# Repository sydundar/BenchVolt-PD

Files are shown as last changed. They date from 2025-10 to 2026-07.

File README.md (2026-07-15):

<div align="center">

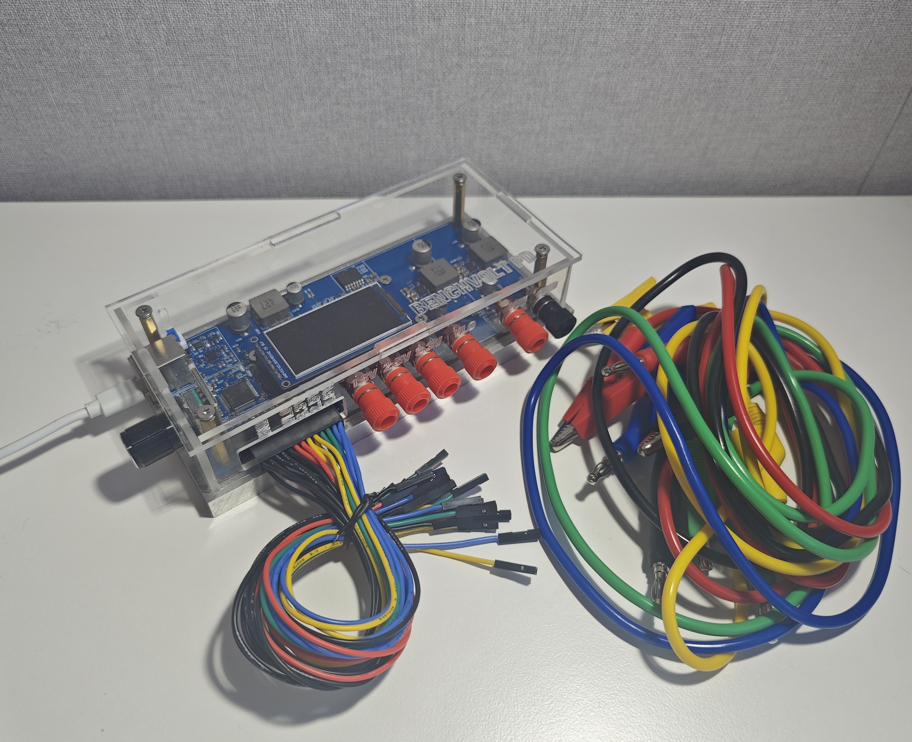
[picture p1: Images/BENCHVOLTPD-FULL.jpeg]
BenchVolt PD Full
  

  <br><br>

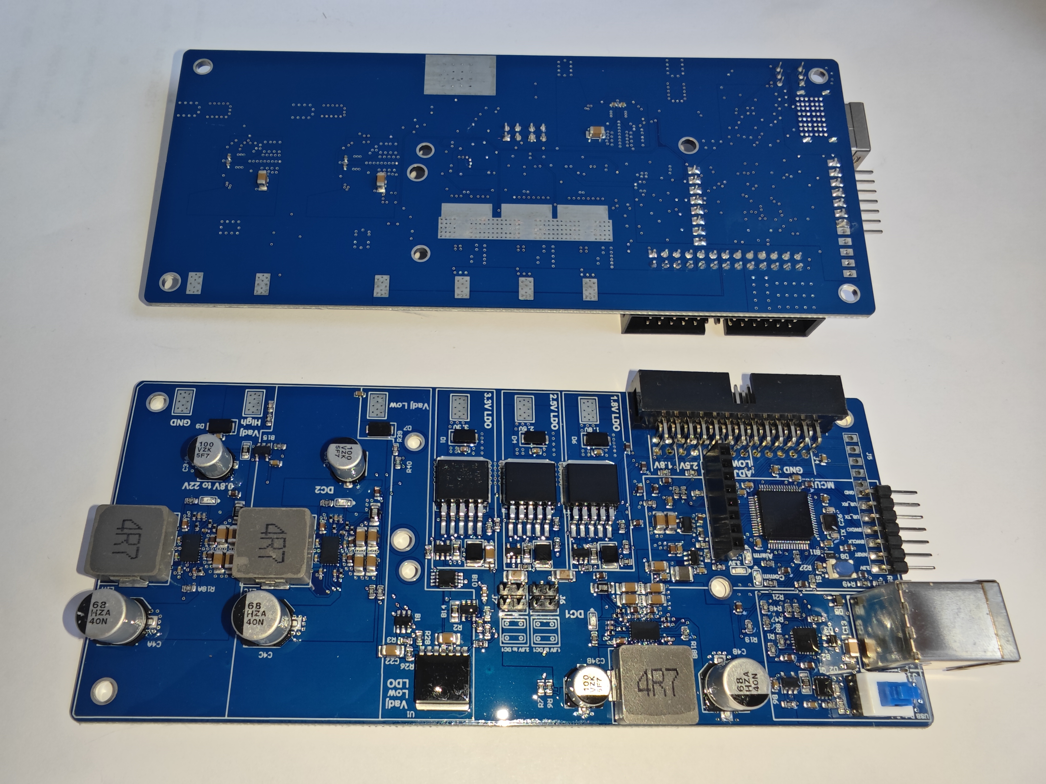
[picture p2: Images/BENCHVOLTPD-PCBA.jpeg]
BenchVolt PD PCBA
  

</div>

# BenchVolt-PD
BenchVolt PD is an open-source, USB-C powered multi-channel lab power supply delivering up to 100 W. Features 5 outputs (0 V–32 V), STM32 control, USB-PD, low-noise LDOs, and a Python GUI. Compact, portable, and perfect for makers and engineers.

BenchVolt PD Block Diagram

**How It Works;**
When **BenchVolt PD** powered on, all regulators and converters start in the **disabled state**. The STM32 microcontroller first powers up and performs safety checks by monitoring **temperature, current, and voltage**. It then **enables** the DC-DC converters, followed by the linear regulators in sequence.

Throughout operation, the MCU **continuously monitors** system all parameters to maintain safe operating conditions.

An **additional safety layer** can be used by setting a power limit through the **USB PD interface**, ensuring the system never exceeds the predefined power threshold. This limit can be configured either from the device’s on-screen menu / rotary encoder or through the Python control interface.

**Each DC-DC converter** is monitored to ensure no more than 5 A is drawn from its output. The **1.8 V** and **2.5 V LDO** regulators share the same **4 V / 5 A** pre-regulator rail, while the **3.3 V** and **Adjustable (0.5 V – 5.5 V)** LDOs share the **5.5 V / 5 A** rail. Therefore, when both LDOs on the same rail are heavily loaded, their combined output current should not exceed 5 A total (typically below 3 A per channel). 

**The third buck-boost output (2.5 V – 32 V)** operates independently and is capable of delivering up to **3A**. Since this channel’s output comes directly from the DC-DC converter, its ripple and noise levels are relatively higher; however, overall stability and performance remain excellent for most applications.

**The other outputs** — regulated through LDOs — provide exceptionally low ripple, offering clean and stable voltages ideal **for sensitive analog and digital circuits.**

Note:

- In theory, the system is capable of delivering up to 100W of total power. However, due to conversion and regulation losses within the DC-DC converters and LDOs, the full **100W cannot be used.** 

- The maximum achievable power depends on the connected USB PD adapter / cable — for example, a 65 W charger will cap the system power at 65 W.

## **Features & Specifications**

### **Power & Outputs**
- Five independent output channels with adjustable voltage and current  
- Fixed outputs: **1.8 V, 2.5 V, 3.3 V @ up to 3 A**  
- Adjustable Output 1: **0.5 V – 5 V @ up to 3 A**  
- Adjustable Output 2: **2.5 V – 32 V @ up to 3 A**  
- 2.54 mm (100 mil) pin headers for powering multiple evaluation boards  
- Arbitrary waveform generation and predefined waveforms (**Square, Sine, Triangle, Ramp**) available on adjustable channels  

---

### **Output Noise & Ripple**
**_Image or Table will be added here..._**
---

### **Arbitrary Functions**
- Number of Points: **1024**  
- Resolution: **12-bit**  
- Point Parameters: **Dwell time** and **Voltage**  
- Dwell Time Range: **4 ms – 16,384 ms**  
- Repetition Rate: **1 – 255 times** or **continuous**

---

### **USB Power Delivery Support**
- USB-C input supporting **PD sink mode**  
- Up to **100 W** USB-PD power input  

---

### **Controls**
- **1.9″ TFT display (170 × 320)** for real-time voltage, current, and PD status  
- **Rotary encoder** for fast menu navigation and fine (5 mV) step adjustments  
- **SCPI command support** for remote programming  
- **Python GUI** for desktop monitoring and control  

---

### **Electronics**
- **Microcontroller:** STM32F030F4
- **USB-PD Controller:** STUSB4500 (sink mode)  
- Configurable **LDOs and boost converters** for precise output regulation  
- **Over-current protection** on all channels  
- **Firmware upgradeable via USB** through the Python interface (no ST-LINK required)

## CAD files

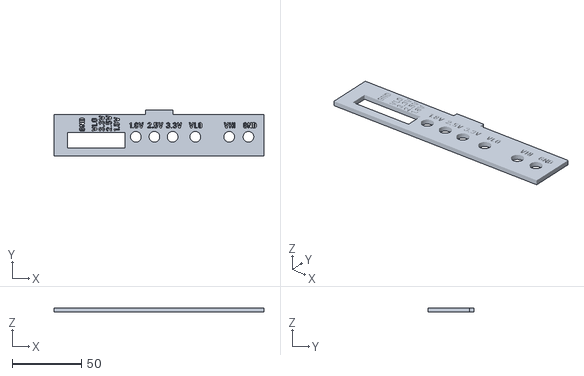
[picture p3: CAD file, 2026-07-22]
Enclosure/Acrylic_Side4.stl
151.8 x 33.0 x 3.00

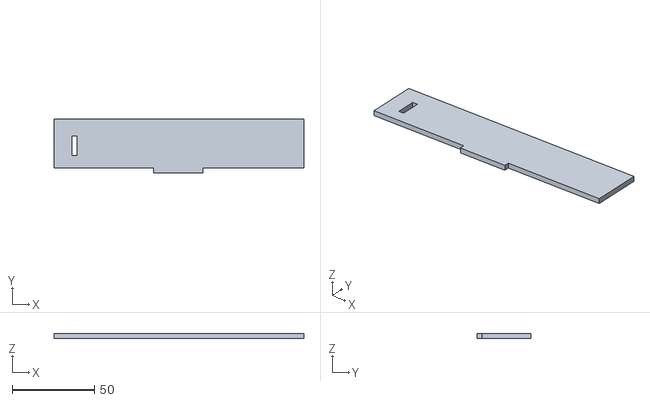
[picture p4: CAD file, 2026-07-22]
Enclosure/Acrylic_Side3.stl
151.8 x 33.0 x 3.00

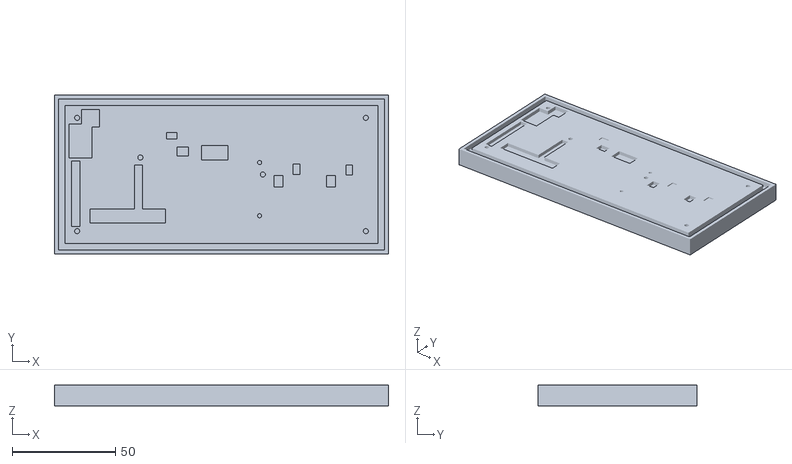
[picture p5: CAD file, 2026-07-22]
Enclosure/Alumunium_Base.stl
162.0 x 77.0 x 10.0

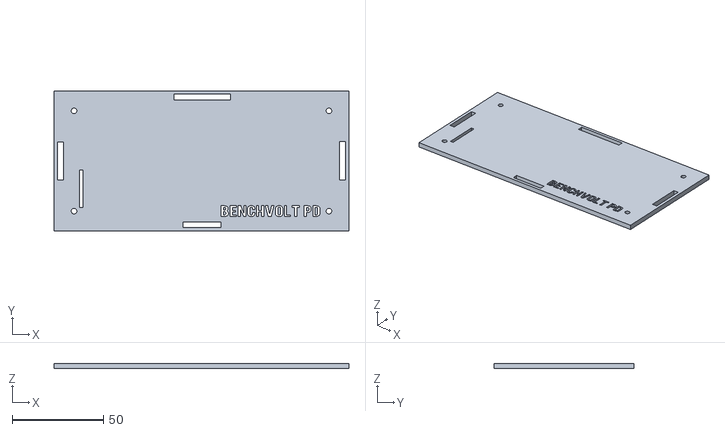
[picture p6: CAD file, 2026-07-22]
Enclosure/Acrylic_Top.stl
162.0 x 77.0 x 3.00

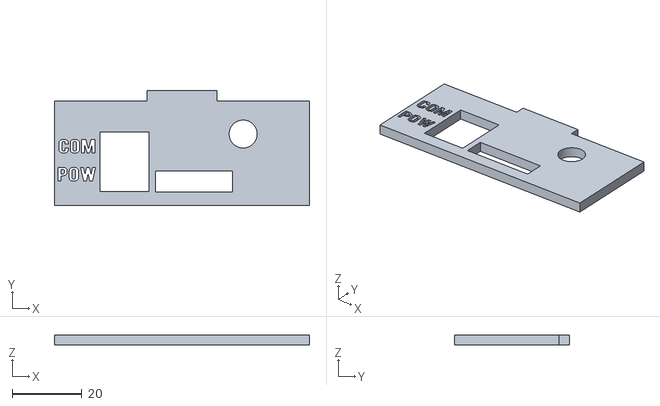
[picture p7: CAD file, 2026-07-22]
Enclosure/Acrylic_Side2.stl
73.0 x 33.0 x 3.00

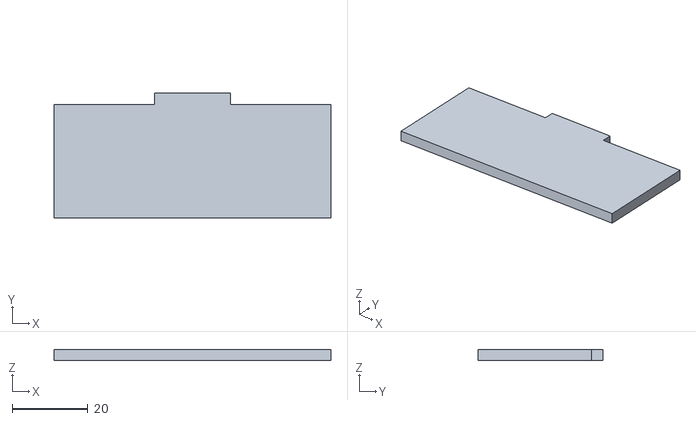
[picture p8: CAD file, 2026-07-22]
Enclosure/Acrylic_Side1.stl
73.0 x 33.0 x 3.00

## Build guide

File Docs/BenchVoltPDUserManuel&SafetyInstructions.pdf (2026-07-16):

# BENCHVOLT PD - User Manual & Safety Instructions

GND
ADJ LOW

3.3V

2.5V

1.8V

3.3V

2.5V

1.8V

ADJ LOW

GND
ADJ HIGH

x5

x2

x2

x2 x2

x2

POW (POWER + DATA)

Use this port when you need both power and data on the same cable

On ➔ | POW = Power + Data
Off➔ POW = Power & COM = Data

COM (DATA ONLY)
Use this port when the device is powered through the POW port and you only need
communication from the PC

STLINK
PROGRAMMING
& DEBUG

The rotary encoder is used to navigate through two menus: Main Menu and Limits Menu. Rotate the encoder clockwise or counterclockwise to navigate between options, and press the center button to select or edit settings. To exit the Limits Menu, navigate to the Exit option in the upper-left corner and press the center button. The interface is designed to be simple and intuitive, allowing users to learn the navigation quickly.

## Accessories

## 2.54 mm Multi-wire Female Jumper Cable

# Safety Instructions

## 5 alligator-to-banana cables

BenchVolt PD complies with the applicable CE and UKCA requirements, including the RoHS (Restriction of Hazardous Substances) and EMC (Electromagnetic Compatibility) directives.

# Warnings

20260528

Use only USB Power Delivery (USB-PD) compliant power adapters and cables.
Verify output voltage and current settings before connecting external hardware.
Incorrect voltage settings may permanently damage connected devices. Do not exceed the maximum rated input or output limits.
Do not short-circuit the outputs intentionally.
All output channels share the same common ground. Do not connect one output channel directly to another output channel.
Turn off the output before connecting or disconnecting external devices. The aluminum base may become warm during prolonged high-power operation.
Additional cooling may be required during continuous high-power usage. Follow proper ESD precautions when touching the input or output connectors.
Do not operate the device in wet, humid, or conductive environments. Disconnect power before opening the enclosure or servicing the device. Ensure adequate ventilation during operation.
Do not use damaged USB cables or accessories.
This product is intended for laboratory, engineering, and development use only.
Keep away from children and unattended operation.
This product is not certified for medical, automotive safety-critical, or life-support applications.

https://github.com/sydundar/BenchVolt-PD

## BENCHVOLT PD – Benutzerhandbuch & Sicherheitshinweise

GND
ADJ LOW

3.3V

2.5V

1.8V

3.3V

2.5V

1.8V

ADJ LOW

GND
ADJ HIGH

x5

x2

x2

x2 x2

x2

POW (POWER + DATA)

Verwenden Sie diesen Anschluss, wenn Sie sowohl Stromversorgung als auch Datenübertragung über dasselbe Kabel benötigen.

Ein ➔ POW = Stromversorgung + Daten Aus ➔ POW = Stromversorgung & COM = Daten

COM (NUR DATEN)

Verwenden Sie diesen
Anschluss, wenn das Gerät über den POW-Anschluss mit Strom versorgt wird und Sie nur die Kommunikation mit dem PC
benötigen.

STLINK
PROGRAMMIERUNG &
DEBUG

Der Drehencoder wird verwendet, um durch zwei Menüs zu navigieren: Hauptmenü und Grenzwerte-Menü. Drehen Sie den Encoder im oder gegen den Uhrzeigersinn, um zwischen den Optionen zu wechseln, und drücken Sie die mittlere Taste, um Einstellungen auszuwählen oder zu bearbeiten.Um das Grenzwerte-Menü zu verlassen, navigieren Sie zur Option „Exit“ oben links und drücken Sie die mittlere Taste.Die Benutzeroberfläche wurde einfach und intuitiv gestaltet, damit sich Benutzer schnell mit der Navigation vertraut machen können.

## Zubehör

## 2,54-mm Mehrdraht-Female-Jumper-Kabel

# Sicherheitshinweise

## 5 Krokodilklemmen-zu-Bananenstecker-Kabel

BenchVolt PD erfüllt die geltenden CE- und UKCA-Anforderungen, einschließlich der RoHS-Richtlinie (Beschränkung gefährlicher Stoffe) sowie der EMC-Richtlinie (Elektromagnetische Verträglichkeit).

# Warnhinweise

20260528

Verwenden Sie ausschließlich USB Power Delivery (USB-PD)-kompatible Netzteile und Kabel.
Überprüfen Sie vor dem Anschließen externer Hardware die Ausgangsspannung und Stromeinstellungen.
Falsche Spannungseinstellungen können angeschlossene Geräte dauerhaft beschädigen.
Überschreiten Sie nicht die maximal zulässigen Ein- oder Ausgangsgrenzen. Schließen Sie die Ausgänge nicht absichtlich kurz.
Alle Ausgangskanäle verwenden dieselbe gemeinsame Masse (GND). Verbinden Sie niemals einen Ausgangskanal direkt mit einem anderen Ausgangskanal. Schalten Sie den Ausgang aus, bevor Sie externe Geräte anschließen oder trennen.
Die Aluminium-Basis kann sich bei längerem Betrieb mit hoher Leistung erwärmen.
Bei dauerhaftem Hochleistungsbetrieb kann zusätzliche Kühlung erforderlich sein.
Beachten Sie geeignete ESD-Schutzmaßnahmen beim Berühren der Ein- oder Ausgangsanschlüsse.
Betreiben Sie das Gerät nicht in feuchten, nassen oder leitfähigen Umgebungen. Trennen Sie die Stromversorgung, bevor Sie das Gehäuse öffnen oder Wartungsarbeiten durchführen.
Sorgen Sie während des Betriebs für ausreichende Belüftung.
Verwenden Sie keine beschädigten USB-Kabel oder Zubehörteile.
Dieses Produkt ist ausschließlich für Labor-, Entwicklungs- und Engineering-Anwendungen vorgesehen.
Von Kindern fernhalten und nicht unbeaufsichtigt betreiben.
Dieses Produkt ist nicht für medizinische Anwendungen, sicherheitskritische Automotive-Systeme oder lebenserhaltende Systeme zertifiziert.

https://github.com/sydundar/BenchVolt-PD

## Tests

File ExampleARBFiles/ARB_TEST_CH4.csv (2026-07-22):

#CONF:MULTIPLIER=1 | REPETITION=0
Voltage_DAC(V) | Dwell_Ticks(ms)
0.50 | 4
1.50 | 4
2.50 | 4
3.10 | 4
4.20 | 4
5.00 | 4
1.40 | 4
1.50 | 4
1.60 | 4
1.70 | 4
1.80 | 4
5.00 | 4

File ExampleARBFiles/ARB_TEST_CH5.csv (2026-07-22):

#CONF:MULTIPLIER=1 | REPETITION=0
Voltage_DAC(V) | Dwell_Ticks(ms)
0.80 | 4
0.90 | 4
1.00 | 4
1.10 | 4
1.20 | 4
1.30 | 4
1.40 | 4
1.50 | 4
1.60 | 4
1.70 | 4
1.80 | 4
1.90 | 4
2.00 | 4
2.10 | 4
2.20 | 4
2.30 | 4
2.40 | 4
2.50 | 4
2.60 | 4
2.70 | 4
2.80 | 4
2.90 | 4
3.00 | 4
3.10 | 4
3.20 | 4
3.30 | 4
3.40 | 4
3.50 | 4
3.60 | 4
3.70 | 4
3.80 | 4
3.90 | 4
4.00 | 4
4.10 | 4
4.20 | 4
4.30 | 4
4.40 | 4
4.50 | 4
4.60 | 4
4.70 | 4
4.80 | 4
4.90 | 4
5.00 | 4
5.10 | 4
5.20 | 4
5.30 | 4
5.40 | 4
5.50 | 4
5.60 | 4
5.70 | 4
5.80 | 4
5.90 | 4
6.00 | 4
6.10 | 4
6.20 | 4
6.30 | 4
6.40 | 4
6.50 | 4
6.60 | 4
6.70 | 4
6.80 | 4
6.90 | 4
7.00 | 4
7.10 | 4
7.20 | 4
7.30 | 4
7.40 | 4
7.50 | 4
7.60 | 4
7.70 | 4
7.80 | 4
7.90 | 4
8.00 | 4
8.10 | 4
8.20 | 4
8.30 | 4
8.40 | 4
8.50 | 4
8.60 | 4
8.70 | 4
8.80 | 4
8.90 | 4
9.00 | 4
9.10 | 4
9.20 | 4
9.30 | 4
9.40 | 4
9.50 | 4
9.60 | 4
9.70 | 4
9.80 | 4
9.90 | 4
10.00 | 4
10.10 | 4
10.20 | 4
10.30 | 4
10.40 | 4
10.50 | 4
10.60 | 4
10.70 | 4
10.80 | 4
10.90 | 4
11.00 | 4
11.10 | 4
11.20 | 4
11.30 | 4
11.40 | 4
11.50 | 4
11.60 | 4
11.70 | 4
11.80 | 4
11.90 | 4
12.00 | 4
12.10 | 4
12.20 | 4
12.30 | 4
12.40 | 4
12.50 | 4
12.60 | 4
12.70 | 4
12.80 | 4
12.90 | 4
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

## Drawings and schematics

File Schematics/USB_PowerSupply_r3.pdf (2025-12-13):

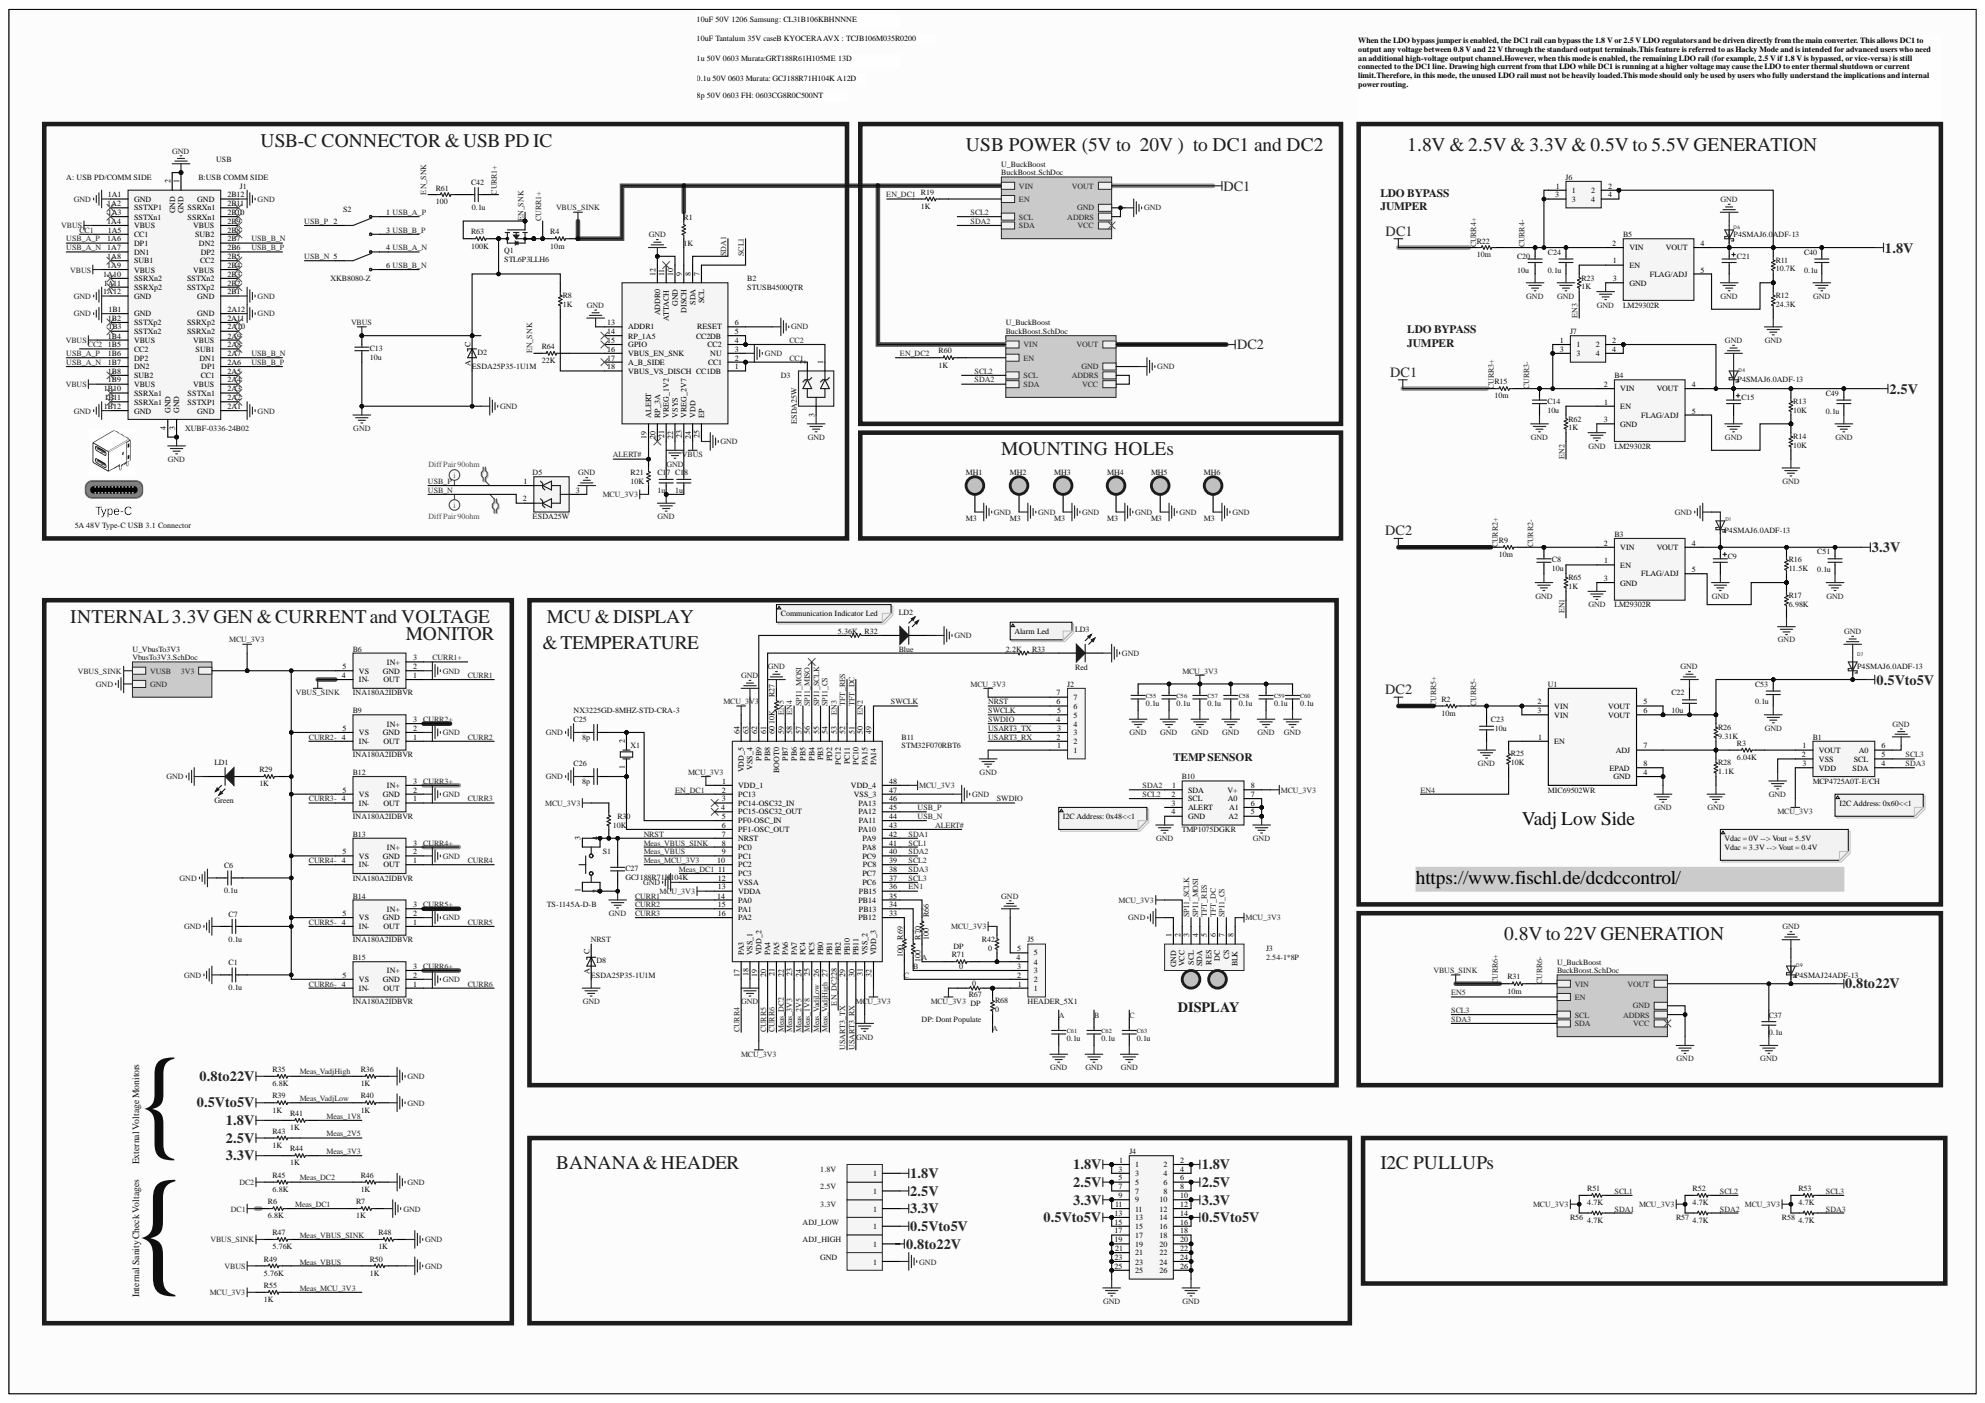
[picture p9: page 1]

When the LDO bypassjumper is enabled, the DC1 rail can bypassthe 1.8 V or 2.5 V LDO regulators and be driven directly from the main converter. This allows DC1 to
output any voltage between 0.8 V and 22 V through the standard output terminals.This feature is referred to as Hacky Mode and is intended for advanced users who need
an additional high-voltage output channel.However, when this mode is enabled, the remaining LDO rail (for example, 2.5 V if 1.8 V is bypassed, or vice-versa) is still
connected to the DC1 line. Drawing high current from that LDO while DC1 is running at a higher voltage may cause the LDO to enter thermal shutdown or current
limit.Therefore, in this mode, the unused LDO rail must not be heavily loaded.This mode should only be used by users who fully understand the implications and internal
power routing.

USB-C CONNECTOR & USB PD IC

A: USB PD/COMM SIDE

SCL 7 SDA 8 DISCH 9 GND 10 ATTACH 11 ADDR0 12

EP 25 VDD 24 VREG_2V7 23 VSYS 22 VREG_1V2 21 RP_3A 20 ALERT 19

https://www.fischl.de/dcdccontrol/

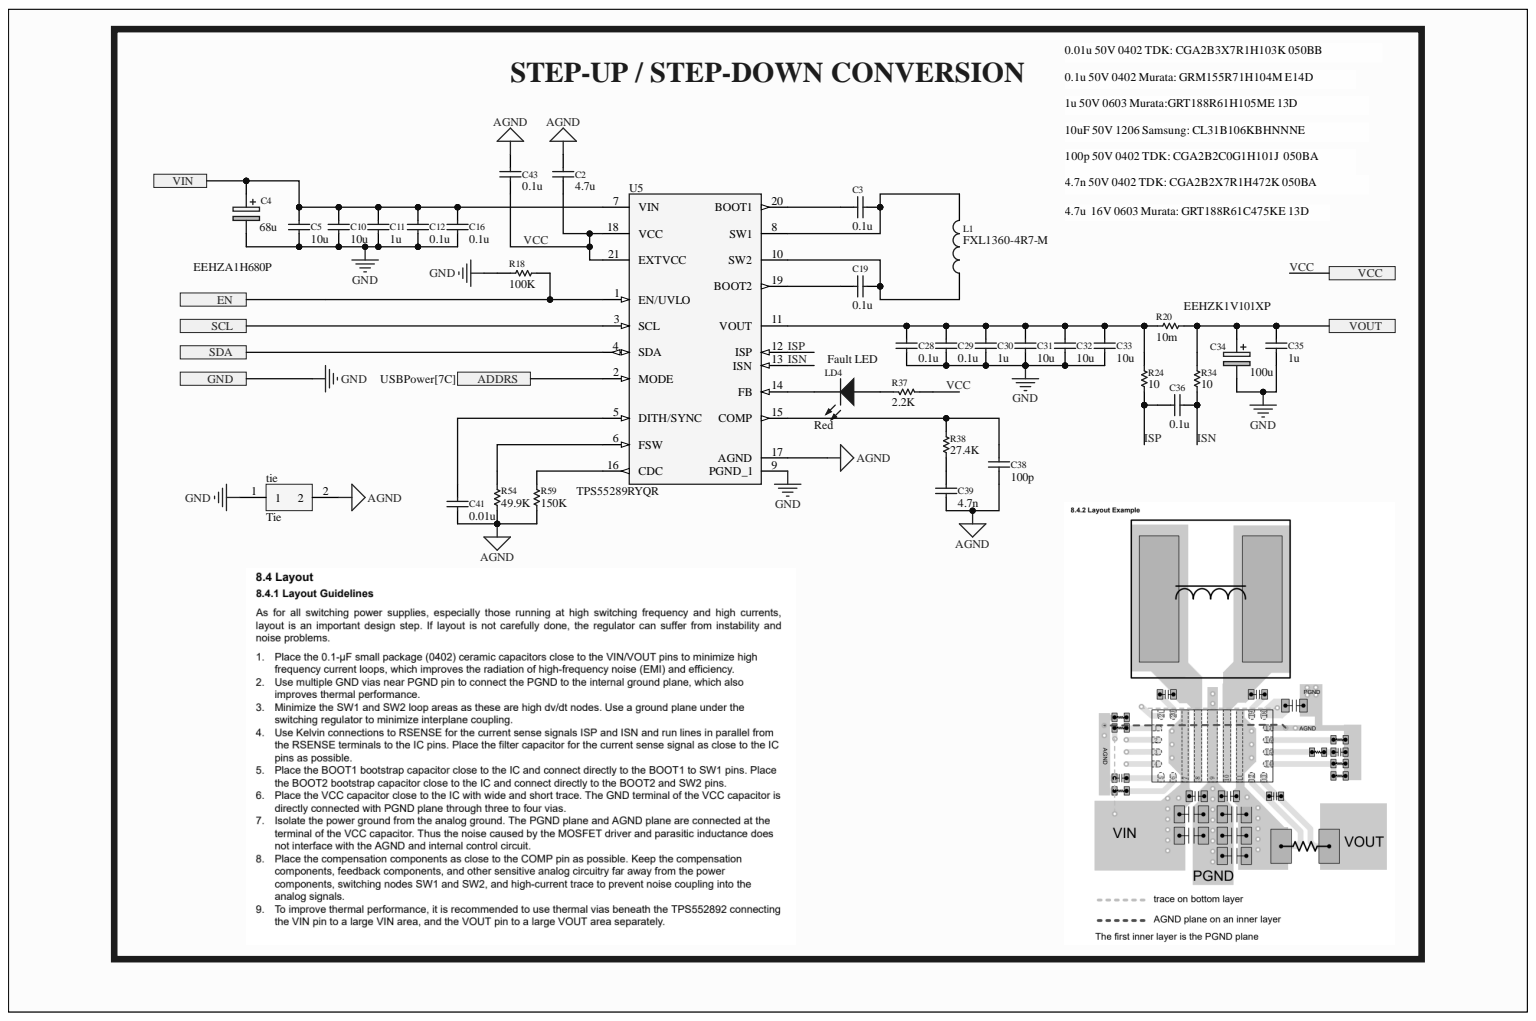
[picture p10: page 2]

STEP-UP / STEP-DOWN CONVERSION

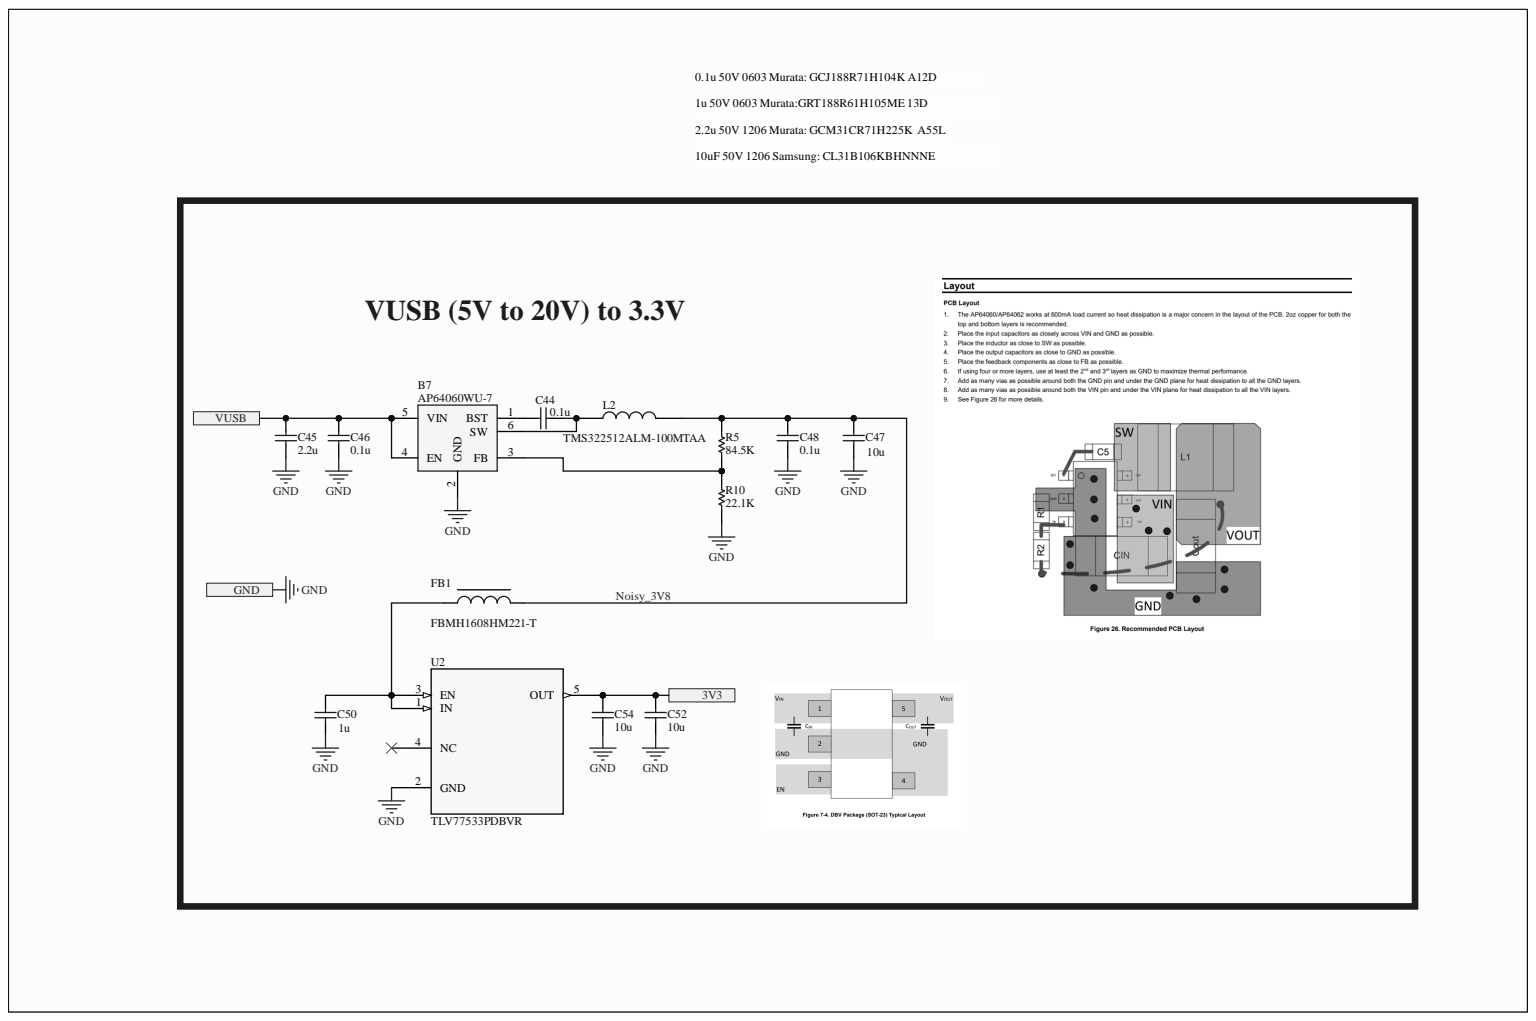
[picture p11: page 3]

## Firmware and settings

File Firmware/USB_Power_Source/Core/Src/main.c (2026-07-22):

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
/* Includes ------------------------------------------------------------------*/
#include "main.h"
#include "usb_device.h"

/* USER CODE BEGIN Includes */
#include "st7789.h"
#include "usbd_cdc_if.h"
#include <stdio.h>
#include "stm32_sw_i2c.h"
#include "stusb4500.h"
#include "USBPD_CUST_NVM_API.h"
#include "USB_PD_defines.h"
#include <soft_i2c_2.h>
#include <soft_i2c_3.h>
#include "stm32f0xx_hal_cortex.h"
/* USER CODE END Includes */

ADC_HandleTypeDef hadc;

SPI_HandleTypeDef hspi1;
DMA_HandleTypeDef hdma_spi1_tx;

UART_HandleTypeDef huart3;

void SystemClock_Config(void);
static void MX_GPIO_Init(void);
static void MX_DMA_Init(void);
static void MX_ADC_Init(void);
static void MX_SPI1_Init(void);
static void MX_USART3_UART_Init(void);
/* USER CODE BEGIN 0 */
uint32_t ARB_CH4_LastMicros = 0;
uint32_t ARB_CH5_LastMicros = 0;
#define ARB_MAX_POINTS 1024
uint16_t arb_dac_buffer[ARB_MAX_POINTS];
uint16_t arb_dwell_buffer[ARB_MAX_POINTS];
bool CH4_ARB_Enabled = false;
bool CH5_ARB_Enabled = false;
uint16_t g_repetition = 0;
uint16_t g_multiplier = 0;
uint16_t g_sample_count = 0;
uint16_t ARB_CH4_Index=0;
uint16_t ARB_CH5_Index=0;

//

void USB_SendMessage(const char *message) {
    if (message == NULL) return;

    uint16_t len = strlen(message);
    uint32_t start_tick = HAL_GetTick();
    uint8_t result;

    do {
        result = CDC_Transmit_FS((uint8_t *)message, len);

        if (result == USBD_BUSY) {
             HAL_Delay(1);
        }

        if ((HAL_GetTick() - start_tick) > 50) {
            break;
        }

    } while (result == USBD_BUSY);
}

const char *welcomeMessage =
"-------------------------------------\r\n"
" Welcome to Fusion USB PD Power Supply\r\n"
" Distributing Power with USB PD Technology\r\n"
"-------------------------------------\r\n"
" System Ready\r\n"
" Firmware Version: 1.0.0\r\n"
" Developed by: Suleyman Y. Dundar\r\n"
"-------------------------------------\r\n";

typedef struct {
    char voltage[6]; // Voltaj değeri
    char current[6]; // Akım değeri
    char power[6];   // Güç değeri
} TableRow;

TableRow tableData[6] = {
    {"00.00", "00.00", "00.00"}, // 1.8V A W
    {"00.00", "00.00", "00.00"}, // 2.5V A W
    {"00.00", "00.00", "00.00"}, // 3.3V A W
    {"00.00", "00.00", "00.00"}, // Vlow A W
    {"00.00", "00.00", "00.00"}, // Vhigh A W
    {"00.00", "00.00", "00.00"}  // Vsink A V (VUSB)
};


float Curr3V3=0;
float Curr2V5=0;
float Curr1V8=0;
float CurrVLow=0;
float CurrVHigh=0;
float CurrVSink=0;

float Currlimit3V3 = 3.00f;
float Currlimit2V5 = 3.00f;
float Currlimit1V8 = 3.00f;
float CurrlimitVLow = 3.00f;
float CurrlimitVHigh = 3.00f;
float CurrlimitVSink = 5.00f;

float TempHighLimit = 75.00f;

float Volt3V3 = 3.30f;
float Volt2V5 = 2.50f;
float Volt1V8 = 1.80f;
float VoltVLow = 5.00f;
float VoltVHigh = 12.00f;
float VoltVSink = 20.00f;


// Max allowed limits
const float MaxCurrlimit3V3    = 3.00f;
const float MaxCurrlimit2V5    = 3.00f;
const float MaxCurrlimit1V8    = 3.00f;
const float MaxCurrlimitVLow   = 3.00f;
const float MaxCurrlimitVHigh  = 3.00f;
const float MaxCurrlimitVSink  = 5.00f;

//const float MaxVolt3V3         = 3.30f;
//const float MaxVolt2V5         = 2.50f;
//const float MaxVolt1V8         = 1.80f;
const float MinVoltVLow        = 0.50f;
const float MinVoltVHigh       = 2.50f;
const float MaxVoltVLow        = 5.00f;
const float MaxVoltVHigh       = 32.00f;
const float MaxVoltVSink       = 20.00f;

TableRow tableDataMenu[6] = {
    {"1.80", "2.00"}, // 1.8V A
    {"2.50", "2.00"}, // 2.5V A
    {"3.30", "2.00"}, // 3.3V A
    {"5.00", "00.00"}, // Vlow A
    {"12.00", "00.00"}, // Vhigh A
    {"20.00", "00.00"}  // Vsink A V (VUSB)
};

// Okunacak ADC kanal sayısı
#define TOTAL_ADC_CHANNELS 17 // IN0-IN12 + IN14 + IN15 + Temperature Sensor


const uint32_t selectedChannels[] = {ADC_CHANNEL_5, ADC_CHANNEL_6, ADC_CHANNEL_7, ADC_CHANNEL_8, ADC_CHANNEL_9, ADC_CHANNEL_10, ADC_CHANNEL_11};
const uint8_t totalChannels = sizeof(selectedChannels) / sizeof(selectedChannels[0]);


//SoftI2C i2c1 = {GPIOA, GPIO_PIN_8, GPIOA, GPIO_PIN_9};  // SCL1 = PA8, SDA1 = PA9
//SoftI2C i2c2 = {GPIOC, GPIO_PIN_8, GPIOC, GPIO_PIN_9};   // SCL2 = PC8, SDA2 = PC9
//SoftI2C i2c3 = {GPIOC, GPIO_PIN_6, GPIOC, GPIO_PIN_7};   // SCL3 = PC6, SDA3 = PC7

float PCBTemperature = 0;

const char *channelNames[] = {
    "Curr1", "Curr2", "Curr3", "Curr4", "Curr5", "Curr6",
    "Bus_6V", "3.3V", "Vlow", "Vhigh", "Vusbsink",
    "Vusb", "MCU_3.3V", "4.0V", "2.5V", "1.8V", 	"Temp"
};

#define VREF 3.3 // Referans Voltajı (V)

typedef enum {
    Ch_Curr1,
    Ch_Curr2,
    Ch_Curr3,
    Ch_Curr4,
    Ch_Curr5,
    Ch_Curr6,
    Ch_Bus_6V,
    Ch_3_3V,
    Ch_Vlow,
    Ch_Vhigh,
    Ch_Vusbsink,
    Ch_Vusb,
    Ch_MCU_3_3V,
	Ch_4V,
    Ch_2_5V,
    Ch_1_8V,
    Ch_Temp
} ChannelName;



ADC_ChannelData channels[TOTAL_ADC_CHANNELS] = {
    {"CurrSink",  0.0 , 2.0}, // 0.01 ohm uzerinden gecen akim x50 Diffopamp ile okunuyor.
    {"Curr3V3",  0.0 , 2.0},
    {"Curr2V5",  0.0 , 2.0},
    {"Curr1V8",  0.0 , 2.0},
    {"CurrVLow",  0.0 , 2.0},
    {"CurrVHigh",  0.0 , 2.0},
    {"Bus_6V",  0.0 , 2.0},  // direnc bolucu normalizasyon
    {"3.3V",  0.0 , 1.0},
    {"Vlow",  0.0 , 2.0},		// direnc bolucu normalizasyon
    {"Vhigh",  0.0 , 7.8},   // direnc bolucu normalizasyon
    {"Vusbsink",  0.0, 6.7},  // direnc bolucu normalizasyon
    {"Vusb",  0.0, 6.7}, // direnc bolucu normalizasyon
    {"MCU_3.3V",  0.0, 1.0},
	{"4.0V",  0.0, 2.0},
    {"2.5V",  0.0, 1.0},
    {"1.8V",  0.0, 1.0},
    {"Temp",  0.0, 1.0}
};



const char *rows_large[] = {
    "1.8V",
    "2.5V",
    "3.3V",
    "V",
    "V",
    "V"
};
const char *rows_small[] = {
    "", // İlk 3 satırda küçük font kullanılmayacak
    "",
    "",
    "Low",
    "High",
    "Sink"
};

uint16_t ARB_CH4_RepetitionCount = 0;
uint16_t ARB_CH5_RepetitionCount = 0;

/* USER CODE BEGIN PV */
#define MAIN_RX_BUFFER_SIZE 256
volatile uint8_t MainRxBuffer[MAIN_RX_BUFFER_SIZE]; // Ana Havuz
volatile uint16_t MainRxHead = 0; // Yazma kafası
volatile uint16_t MainRxTail = 0; // Okuma kafası


void delay_cycles(volatile uint32_t cycles) {
    while(cycles--) {
        __NOP();
    }
}

// Havuza veri atma fonksiyonu (Interrupt kullanacak)
void Store_USB_Data(uint8_t* Buf, uint32_t Len) {
    for (uint32_t i = 0; i < Len; i++) {
        uint16_t nextHead = (MainRxHead + 1) % MAIN_RX_BUFFER_SIZE;
        if (nextHead != MainRxTail) { // Havuz dolmadıysa yaz
            MainRxBuffer[MainRxHead] = Buf[i];
            MainRxHead = nextHead;
        }
    }
}

// Havuzdan veri okuma fonksiyonu (Main kullanacak)
// Veri yoksa -1 döner, varsa karakteri döner (0-255)
int16_t Read_USB_Data(void) {
    if (MainRxHead == MainRxTail) {
        return -1; // Veri yok
    }
    uint8_t c = MainRxBuffer[MainRxTail];
    MainRxTail = (MainRxTail + 1) % MAIN_RX_BUFFER_SIZE;
    return c;
}
/* USER CODE END PV */

float ConvertAdcToTemperature(float vTempSensor) {
    // Sabit değerler (koddan alınmış)
    const int32_t INTERNAL_TEMPSENSOR_V30 = 1430;       // 30°C'deki sensör voltajı (mV)
    const int32_t INTERNAL_TEMPSENSOR_AVGSLOPE = 4300;  // Sensör eğimi (uV/°C)

    // Sıcaklık hesaplama (°C)
    float temperature = ((vTempSensor - INTERNAL_TEMPSENSOR_V30) / INTERNAL_TEMPSENSOR_AVGSLOPE) + 30.0f;

    return temperature;
}

volatile uint32_t UptimeMillis = 0;



uint32_t micros(void)
{
    uint32_t ms;
    uint32_t st;

    do
    {
        ms = UptimeMillis;
        st = SysTick->VAL;
    } while (ms != UptimeMillis);

    return ms * 1000 - st / ((SysTick->LOAD + 1) / 1000);
}


GPIO_PinState prevS1 = GPIO_PIN_SET;
GPIO_PinState prevS2 = GPIO_PIN_SET;
GPIO_PinState prevKey = GPIO_PIN_SET;

GPIO_PinState currS1;
GPIO_PinState currS2;
GPIO_PinState currKey;

volatile bool rotaryPressed = false;
bool SkpFirstRunCheck = false;



void CheckRotaryButtonPressOnly(void) {
    static GPIO_PinState prevKey = GPIO_PIN_SET;
    static uint32_t lastDebounceTime = 0;
    const uint32_t debounceDelay = 150;

    //GPIO_PinState currKey = HAL_GPIO_ReadPin(GPIOB, GPIO_PIN_14);
    uint8_t currKey = (GPIOB->IDR & GPIO_PIN_14) ? 1 : 0;

    if (prevKey == GPIO_PIN_SET && currKey == GPIO_PIN_RESET) {
        uint32_t now = HAL_GetTick();
        if (now - lastDebounceTime > debounceDelay) {
            lastDebounceTime = now;
            OnRotaryPressed();  // Menüye giriş/çıkış buradan

            /*
             * Do not send USB debug text from the button path.
             * CDC_Transmit_FS can become busy and make the UI look locked,
             * especially while the TFT is also being updated.
             */
            //USB_SendMessage("OnRotaryPressed()");

            SkpFirstRunCheck = false;
        }
    }

    prevKey = currKey;
}

void HAL_SPI_TxCpltCallback(SPI_HandleTypeDef *hspi)
{
    if (hspi->Instance == SPI1)
    {
        // SPI1_CS_GPIO_Port->BSRR = (uint32_t)SPI1_CS_Pin; // CS_SET() - Pin High
        ST7789_UnSelect();
    }
}

void StepwiseUpdateDisplay() {
    static uint8_t currentStep = 0;
    static uint8_t row = 0;


    switch (currentStep) {
        case 0:

            PrepData(channels);
            row = 0;
            break;


        case 1:  ST7789_WriteString(54, 30 + row * 25, tableData[0].voltage, Font_11x18, YELLOW, BLACK);  break;
        case 2:  ST7789_WriteString(118, 30 + row * 25, tableData[0].current, Font_11x18, YELLOW, BLACK); break;
        case 3:  ST7789_WriteString(178, 30 + row * 25, tableData[0].power,   Font_11x18, YELLOW, BLACK); break;

        case 4:  row = 1; ST7789_WriteString(54, 30 + row * 25, tableData[1].voltage, Font_11x18, YELLOW, BLACK); break;
        case 5:  ST7789_WriteString(118, 30 + row * 25, tableData[1].current, Font_11x18, YELLOW, BLACK); break;
        case 6:  ST7789_WriteString(178, 30 + row * 25, tableData[1].power,   Font_11x18, YELLOW, BLACK); break;

        case 7:  row = 2; ST7789_WriteString(54, 30 + row * 25, tableData[2].voltage, Font_11x18, YELLOW, BLACK); break;
        case 8:  ST7789_WriteString(118, 30 + row * 25, tableData[2].current, Font_11x18, YELLOW, BLACK); break;
        case 9:  ST7789_WriteString(178, 30 + row * 25, tableData[2].power,   Font_11x18, YELLOW, BLACK); break;

        case 10: row = 3; ST7789_WriteString(54, 30 + row * 25, tableData[3].voltage, Font_11x18, YELLOW, BLACK); break;
        case 11: ST7789_WriteString(118, 30 + row * 25, tableData[3].current, Font_11x18, YELLOW, BLACK); break;
        case 12: ST7789_WriteString(178, 30 + row * 25, tableData[3].power,   Font_11x18, YELLOW, BLACK); break;

        case 13: row = 4; ST7789_WriteString(54, 30 + row * 25, tableData[4].voltage, Font_11x18, YELLOW, BLACK); break;
        case 14: ST7789_WriteString(118, 30 + row * 25, tableData[4].current, Font_11x18, YELLOW, BLACK); break;
        case 15: ST7789_WriteString(178, 30 + row * 25, tableData[4].power,   Font_11x18, YELLOW, BLACK); break;

        case 16: row = 5; ST7789_WriteString(54, 30 + row * 25, tableData[5].voltage, Font_11x18, LGRAY, BLACK); break;
        case 17: ST7789_WriteString(118, 30 + row * 25, tableData[5].current, Font_11x18, LGRAY, BLACK); break;
        case 18: ST7789_WriteString(178, 30 + row * 25, tableData[5].power,   Font_11x18, LGRAY, BLACK); break;

        case 19: PCBTemperature = read_temp(0);
        case 20:
        	char buffer[16];
			snprintf(buffer, sizeof(buffer), "Temp:%.2fC", PCBTemperature);
			ST7789_WriteString(235, 15, buffer, Font_7x10, WHITE, BLACK);
			break;

    }

    currentStep++;
    if (currentStep > 20)
    	currentStep = 0;
}



bool channelEnabled[5] = {false, false, false, false, false};         // Gerçek kanal durumu
bool prevChannelEnabled[5] = {false, false, false, false, false}; // Önceki durum (ilk turda farklı olacak)

void CheckAndDisableOvercurrent() {
    int y_position ;

    // 3.3V - index 2
    y_position = 30 + 2 * 25;
    if (Curr3V3 > Currlimit3V3) {
        HAL_GPIO_WritePin(EN1_GPIO_Port, EN1_Pin, GPIO_PIN_RESET);
        channelEnabled[2] = false;
    }
    if (channelEnabled[2] != prevChannelEnabled[2]) {
        //ST7789_DrawFilledCircle(240, y_position + 8, 6, channelEnabled[2] ? GREEN : RED);
        DrawChannelCircle(2, channelEnabled[2]);
        prevChannelEnabled[2] = channelEnabled[2];
    }

    // 2.5V - index 1
    y_position = 30 + 1 * 25;
    if (Curr2V5 > Currlimit2V5) {
        HAL_GPIO_WritePin(EN2_GPIO_Port, EN2_Pin, GPIO_PIN_RESET);
        channelEnabled[1] = false;
    }
    if (channelEnabled[1] != prevChannelEnabled[1]) {
        //ST7789_DrawFilledCircle(240, y_position + 8, 6, channelEnabled[1] ? GREEN : RED);
        DrawChannelCircle(1, channelEnabled[1]);
        prevChannelEnabled[1] = channelEnabled[1];
    }

    // 1.8V - index 0
    y_position = 30 + 0 * 25;
    if (Curr1V8 > Currlimit1V8) {
        HAL_GPIO_WritePin(EN3_GPIO_Port, EN3_Pin, GPIO_PIN_RESET);
        channelEnabled[0] = false;
    }
    if (channelEnabled[0] != prevChannelEnabled[0]) {
        //ST7789_DrawFilledCircle(240, y_position + 8, 6, channelEnabled[0] ? GREEN : RED);
    	DrawChannelCircle(0, channelEnabled[0]);
        prevChannelEnabled[0] = channelEnabled[0];
    }

    // VLow - index 3
    y_position = 30 + 3 * 25;
    if (CurrVLow > CurrlimitVLow) {
        HAL_GPIO_WritePin(EN4_GPIO_Port, EN4_Pin, GPIO_PIN_RESET);
        channelEnabled[3] = false;
    }
    if (channelEnabled[3] != prevChannelEnabled[3]) {
    	//ST7789_DrawFilledCircle(240, y_position + 8, 6, channelEnabled[3] ? GREEN : RED);
    	DrawChannelCircle(3, channelEnabled[3]);
        prevChannelEnabled[3] = channelEnabled[3];
    }

    // VHigh - index 4
    y_position = 30 + 4 * 25;
    if (CurrVHigh > CurrlimitVHigh) {
        HAL_GPIO_WritePin(EN5_GPIO_Port, EN5_Pin, GPIO_PIN_RESET);
        channelEnabled[4] = false;
    }
    if (channelEnabled[4] != prevChannelEnabled[4]) {
    	//ST7789_DrawFilledCircle(240, y_position + 8, 6, channelEnabled[4] ? GREEN : RED);
    	DrawChannelCircle(4, channelEnabled[4]);
        prevChannelEnabled[4] = channelEnabled[4];
    }


}
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
int main(void)
{


  /* MCU Configuration--------------------------------------------------------*/
  HAL_Init();

  /* Configure the system clock */
  SystemClock_Config();

  /* Initialize only GPIO for Test */
  MX_GPIO_Init();



  MX_DMA_Init();
  MX_ADC_Init();
  /* USER CODE BEGIN CLKSET */
  hspi1.Init.BaudRatePrescaler = SPI_BAUDRATEPRESCALER_2;
  /* USER CODE BEGIN CLKSET */
  MX_SPI1_Init();
  MX_USART3_UART_Init();
  __HAL_RCC_USB_CLK_ENABLE();
  USB->BCDR |= USB_BCDR_DPPU;
  MX_USB_DEVICE_Init();

  /* USER CODE BEGIN 2 */
  __enable_irq(); // Kesmeleri aç


  /* USER CODE END 2 */
  SetPowerEnable("EN3V3", false);
  SetPowerEnable("EN2V5", false);
  SetPowerEnable("EN1V8", false);
  SetPowerEnable("ENLow", false);
  SetPowerEnable("ENHigh", false);
  SetPowerEnable("ENDC1", false);
  SetPowerEnable("ENDC2", false);

  // ADC Kalibrasyon
  if (HAL_ADCEx_Calibration_Start(&hadc) != HAL_OK) {
      USB_SendMessage("ADC calibration failed\r\n");
      Error_Handler();
  }


  ST7789_Init();
  ST7789_Fill_Color(BLACK);

  DisplayTableWithGrid();
  HAL_Delay(100);

  I2C_init();
  I2C2_init();
  I2C3_init();

  DrawMenuArrowsAndCirclesInit();

  SetPowerEnable("EN3V3", true);
  SetPowerEnable("EN2V5", true);
  SetPowerEnable("EN1V8", true);
  SetPowerEnable("ENLow", true);
  SetPowerEnable("ENHigh",true);
  SetPowerEnable("ENDC1", true);
  SetPowerEnable("ENDC2", true);

  UpdateChannelState(0, true);
  UpdateChannelState(1, true);
  UpdateChannelState(2, true);
  UpdateChannelState(3, true);
  UpdateChannelState(4, true);
  for (int i = 0; i < 5; i++) {
      prevChannelEnabled[i] = !channelEnabled[i];
  }
  DrawMenuArrowsAndCirclesInit();

  HAL_Delay(100);
  InitVAdjHigh(); HAL_Delay(50);
  InitDC1(); HAL_Delay(50);
  InitDC2(); HAL_Delay(50);

  EnVAdjHighOutput(true); HAL_Delay(50);
  EnDC1Output(true); HAL_Delay(50);
  EnDC2Output(true); HAL_Delay(50);

  SetVoltageDC1(3.0); HAL_Delay(50);
  SetVoltageDC2(5.5); HAL_Delay(50);
  SetVadjLVoltage(5.0); HAL_Delay(50);
  SetVoltageVAdjHigh(12.0); HAL_Delay(50);

  SetDC1CurrentLimit(6.0); HAL_Delay(50);
  SetDC2CurrentLimit(6.0); HAL_Delay(50);
  SetVAdjHighCurrentLimit(6.0); HAL_Delay(50);


  /* * CRITICAL WARNING: ACTIVE PROBING & INFINITE BOOT-LOOP HAZARD
   * -------------------------------------------------------------------------
   * This function sends PD commands (like 'PD_GET_SRC_CAP' or 'PD_SOFT_RESET')
   * to negotiate the max PDO. However, many vendor-specific chargers and power banks
   * treat these early commands as protocol violations and react by executing a
   * HARD RESET (momentarily dropping VBUS to 0V).
   * * * CONSEQUENCE: Since the MCU is directly powered by VBUS without a battery backup,
   * this power drop causes an immediate hardware reset. Upon reboot, the MCU executes
   * this exact line again, triggering an inescapable infinite boot-loop.
   * * * ACTION: If rapid rebooting occurs, comment out this line. Rely on passive
   * PDO reading (sniffer mode) at startup and only trigger active negotiation via UI.
   * -------------------------------------------------------------------------
   NegotiatetoMaxPDO();
   */



    /* USER CODE END 2 */

  /* Infinite loop */
  /* USER CODE BEGIN WHILE */

    while (1)
    {
      /* USER CODE END WHILE */

      /* USER CODE BEGIN 3 */


  	  int16_t data = Read_USB_Data();

  	 if (data != -1) {
  	          Remote_Parse_Byte((uint8_t)data); // COmmand process
  	 }

  	  uint32_t currentTime = micros();
  	  GPIOB->ODR ^= LED_BLUE_Pin;

		CheckRotaryButtonPressOnly();


		if (rotaryPressed) {
			rotaryPressed = false;
			RedrawAllTableRows();
			SkpFirstRunCheck = false;
		}

		/*
		 * Draw pending Menu text color update here, not inside rotary handler.
		 * This avoids locking caused by ST7789_WriteString() during selection change.
		 */
		if (quickMenuTextUpdatePending && menuState != MENU_LIMIT_SET)
		{
			quickMenuTextUpdatePending = false;
			ST7789_WriteString(2, 4, "Menu", Font_11x18, quickMenuTextRequestedColor, BLACK);
		}



         // High Temperature reached turn off all channels.
         if (PCBTemperature > TempHighLimit)
         {
      	   SetPowerEnable("EN3V3", false);
      	   SetPowerEnable("EN2V5", false);
      	   SetPowerEnable("EN1V8", false);
      	   SetPowerEnable("ENLow", false);
      	   SetPowerEnable("ENHigh", false);
      	   SetPowerEnable("ENDC1", false);
      	   SetPowerEnable("ENDC2", false);

      	   UpdateChannelState(0,false);
      	   UpdateChannelState(1,false);
      	   UpdateChannelState(2,false);
      	   UpdateChannelState(3,false);
      	   UpdateChannelState(4,false);

         }


        if (menuState == MENU_LIMIT_SET)
        {
            if ((currentTime - lastTimeD) > 100000) {
          	  //WriteExtraInfoStepByStep();
          	  lastTimeD = currentTime;
            }
      	  continue;
        }



        GetADCValuesWithStatsFast();
        CheckAndDisableOvercurrent();


        // call every 500ms
         if ((currentTime - lastTimeA) >= 500000) {
             lastTimeA = currentTime;   //
         }

         if ((currentTime - lastTimeB) > 30000) {
      	   StepwiseUpdateDisplay();
             lastTimeB = currentTime;
         }



         uint32_t elapsed = micros() - currentTime;
         if (elapsed >= 4000 && SkpFirstRunCheck)
            {
                HAL_GPIO_WritePin(LED_RED_GPIO_Port, LED_RED_Pin, GPIO_PIN_SET); //
            }

         SkpFirstRunCheck = true;


  	  // ARB Genaration ////////////////////////////////

         if (CH4_ARB_Enabled)
         {
             uint32_t target_delay = arb_dwell_buffer[ARB_CH4_Index] * g_multiplier * 1000;

             if (currentTime - ARB_CH4_LastMicros >= target_delay)
             {
                 SetVadjLVoltage((float)arb_dac_buffer[ARB_CH4_Index] / 100.0f);

                 ARB_CH4_LastMicros = currentTime;
                 ARB_CH4_Index++;

                 // End of buffer
                 if (ARB_CH4_Index >= g_sample_count)
                 {
                     ARB_CH4_Index = 0;
                     ARB_CH4_RepetitionCount++;

                     // Stop after requested repetitions
                     if (ARB_CH4_RepetitionCount >= g_repetition && g_repetition !=0)
                     {
                         CH4_ARB_Enabled = false;
                         ARB_CH4_Index = 0;
                         ARB_CH4_RepetitionCount = 0;
                     }
                 }
             }
         }
         else if (CH5_ARB_Enabled)
         {
             uint32_t target_delay = arb_dwell_buffer[ARB_CH5_Index] * g_multiplier * 1000;

             if (currentTime - ARB_CH5_LastMicros >= target_delay)
             {
                 VAdjHigh_SetVoltage((float)arb_dac_buffer[ARB_CH5_Index] / 100.0f);

                 ARB_CH5_LastMicros = currentTime;
                 ARB_CH5_Index++;

                 // End of buffer
                 if (ARB_CH5_Index >= g_sample_count)
                 {
                     ARB_CH5_Index = 0;
                     ARB_CH5_RepetitionCount++;

                     // Stop after requested repetitions
                     if (ARB_CH5_RepetitionCount >= g_repetition  && g_repetition !=0)
                     {
                         CH5_ARB_Enabled = false;
                         ARB_CH5_Index = 0;
                         ARB_CH5_RepetitionCount = 0;
                     }
                 }
             }
         }
  	  ////////////////////////////////


    }

  /* USER CODE END 3 */
}
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


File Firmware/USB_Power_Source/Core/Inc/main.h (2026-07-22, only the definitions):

#define EN_DC1_Pin GPIO_PIN_13
#define EN_DC1_GPIO_Port GPIOC
#define EN_DC2_Pin GPIO_PIN_2
#define EN_DC2_GPIO_Port GPIOB
#define DT_Pin GPIO_PIN_13
#define DT_GPIO_Port GPIOB
#define SW_Pin GPIO_PIN_14
#define SW_GPIO_Port GPIOB
#define EN1_Pin GPIO_PIN_15
#define EN1_GPIO_Port GPIOB
#define SCL3_Pin GPIO_PIN_6
#define SCL3_GPIO_Port GPIOC
#define SDA3_Pin GPIO_PIN_7
#define SDA3_GPIO_Port GPIOC
#define SCL2_Pin GPIO_PIN_8
#define SCL2_GPIO_Port GPIOC
#define SDA2_Pin GPIO_PIN_9
#define SDA2_GPIO_Port GPIOC
#define SCL1_Pin GPIO_PIN_8
#define SCL1_GPIO_Port GPIOA
#define SDA1_Pin GPIO_PIN_9
#define SDA1_GPIO_Port GPIOA
#define ALERT_Pin GPIO_PIN_10
#define ALERT_GPIO_Port GPIOA
#define EN2_Pin GPIO_PIN_15
#define EN2_GPIO_Port GPIOA
#define TFT_DC_Pin GPIO_PIN_10
#define TFT_DC_GPIO_Port GPIOC
#define TFT_RES_Pin GPIO_PIN_11
#define TFT_RES_GPIO_Port GPIOC
#define EN3_Pin GPIO_PIN_12
#define EN3_GPIO_Port GPIOC
#define SPI1_CS_Pin GPIO_PIN_2
#define SPI1_CS_GPIO_Port GPIOD
#define EN4_Pin GPIO_PIN_6
#define EN4_GPIO_Port GPIOB
#define EN5_Pin GPIO_PIN_7
#define EN5_GPIO_Port GPIOB
#define LED_RED_Pin GPIO_PIN_8
#define LED_RED_GPIO_Port GPIOB
#define LED_BLUE_Pin GPIO_PIN_9
#define LED_BLUE_GPIO_Port GPIOB

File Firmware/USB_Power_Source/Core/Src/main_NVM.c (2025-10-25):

//
///* Defines ------------------------------------------------------------------*/
//#define READ_NVM 1   //0:false, 1:true
//#define FLASH_NVM 1   //0:false, 1:true
//#define VERIFY_NVM 1   //0:false, 1:true
//
//
///* Includes ------------------------------------------------------------------*/
//#include <stdio.h> //for printf()
//
///* USER CODE BEGIN Includes */
//#include "USB_PD_defines.h"
//#include "USBPD_CUST_NVM_API.h"
///* USER CODE END Includes */
//
//
///* USER CODE BEGIN PV */
///* Private variables ---------------------------------------------------------*/
//extern I2C_HandleTypeDef *hi2c[2];
//extern unsigned int I2cDeviceID_7bit;
///* USER CODE END PV */
//
//
//int main_NVM(void)
//{
//
//    /* USER CODE BEGIN 2 */
//    int status;
//
//
//    hi2c[0]= &hi2c1;
//    hi2c[1]= &hi2c2;
//    I2cDeviceID_7bit = STUSBxx_DEVICEID_7BIT;
//
//
//    printf("*** STUSB NVM programming ***\r\n");
//
//
//    //Reset STUSBxx
//    HAL_GPIO_WritePin(Reset_GPIO_Port,Reset_Pin,GPIO_PIN_SET);
//    HAL_Delay(1);
//    HAL_GPIO_WritePin(Reset_GPIO_Port,Reset_Pin,GPIO_PIN_RESET);
//    HAL_Delay(200);
//
//
//#if READ_NVM
//    {
//        unsigned char NVM_Sectors[5][8] = {0, 0};
//        status = nvm_read( &NVM_Sectors[0][0], sizeof(NVM_Sectors) );
//        if(status != 0) //Error
//        {
//            printf("Error NVM read\r\n");
//            return -1;
//        }
//    }
//#endif //READ_NVM
//
//
//#if FLASH_NVM
//    {
//        uint8_t Buffer;
//        status = I2C_Read_USB_PD(0,DEVICE_ID, &Buffer, 1);
//        if(status != 0)  { printf("Error I2C \r\n"); return -1;}
//
//        if(Buffer & ID_Reg >= CUT)
//        {
//            status = nvm_flash();
//            if ( status != 0)
//                printf("STUSB Flashing Failed \r\n"); // Port 0 mean I2C1 For I2C2 change to Port 1
//            else
//                printf("STUSB Flashing OK\r\n");
//        }
//        else  printf("STUSB Flashing Not done : Bad version\r\n");
//    }
//#endif //FLASH_NVM
//
//
//#if VERIFY_NVM
//    {
//        uint8_t Verification_Sector[8];
//        uint8_t Sector40[5][8];
//
//        extern uint8_t Sector0[8];
//        extern uint8_t Sector1[8];
//        extern uint8_t Sector2[8];
//        extern uint8_t Sector3[8];
//        extern uint8_t Sector4[8];
//
//
//        for(int i=0; i<8; i++) //copy sectors to 40byte array
//        {
//            Sector40[0][i] = Sector0[i];
//            Sector40[1][i] = Sector1[i];
//            Sector40[2][i] = Sector2[i];
//            Sector40[3][i] = Sector3[i];
//            Sector40[4][i] = Sector4[i];
//        }
//
//        if (CUST_EnterReadMode(0) == 0 ) //OK
//        {
//            for(int bk=0; bk<5; bk++)
//            {
//                if (CUST_ReadSector(0,bk, &Verification_Sector[0]) ==0)
//                {
//                    if (  *(uint64_t *) Verification_Sector != *(uint64_t *) (Sector40[bk])   )
//                    {
//                        for ( int j = 0 ;j < 8 ; j++)
//                        {
//                            if (  Verification_Sector[j] != Sector40[bk][j])
//                                printf("NVM verification issue byte %i bank %i \r\n", j, bk);
//                        }
//                    }
//                    else   printf("NVM verification bank %i : OK \r\n", bk);
//                }
//                else  printf("NVM read bank %i : failed \r\n", bk);
//            }
//        }
//        else  printf("NVM read initialization: failed \r\n");
//    }
//#endif //VERIFY_NVM
//
//
//    /* USER CODE END 2 */
//
//    return 0;
//}
//

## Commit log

2025-12-17 Delete Schematics/Schmatics Picture will be shared during campaign.txt
    file deleted
2025-12-17 Delete Schematics/BenchVoltPD.svg
    Old Block Diagram Deleted
2026-07-22 Add STM32 firmware: bootloader and USB_Power_Source
    [USB_Power_Source Debug.cfg]

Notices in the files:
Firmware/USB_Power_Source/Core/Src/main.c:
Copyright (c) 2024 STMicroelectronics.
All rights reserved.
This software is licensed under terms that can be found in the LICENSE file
